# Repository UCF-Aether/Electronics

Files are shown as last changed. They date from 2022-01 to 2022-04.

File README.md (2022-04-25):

<p align="center">
  
</p>

# Aether Electronics
The schematic is viewable as a PDF in the latest release. To view in KiCad, make sure you have KiCad 6 installed, and simply clone the repo and open `aether.kicad_pro`.

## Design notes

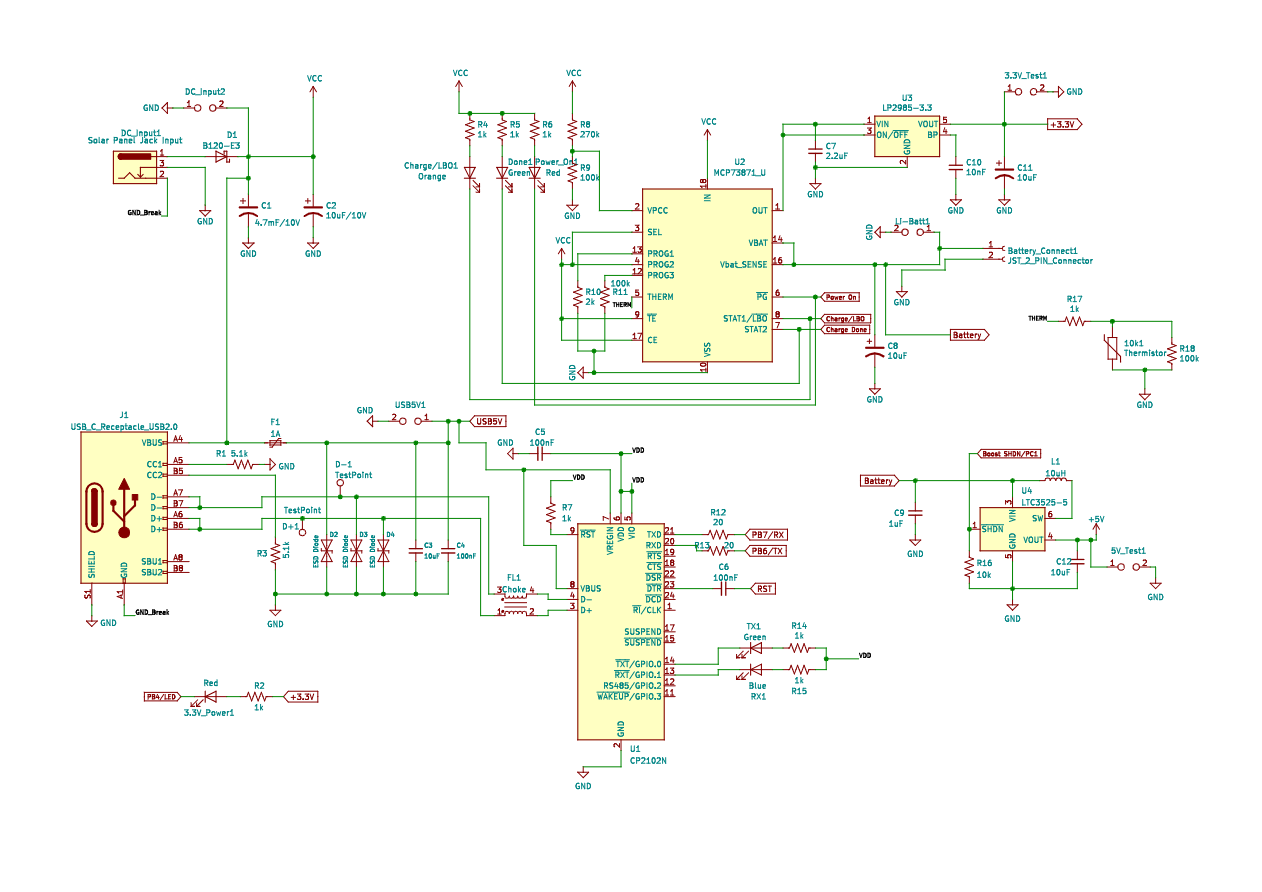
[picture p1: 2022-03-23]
Schematic Images/Power_Schematic_00_00.jpg

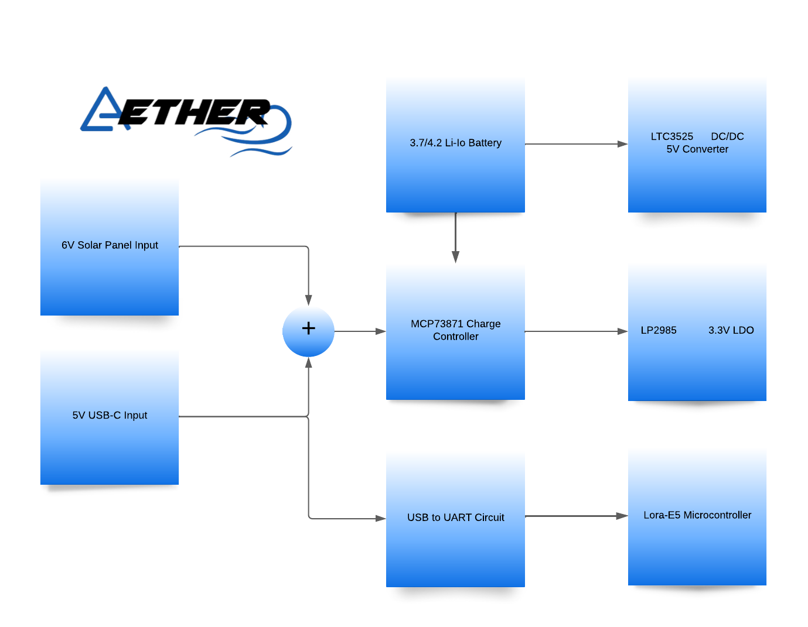
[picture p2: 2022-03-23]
Schematic Images/Aether Power Subsystem Block Diagram.png

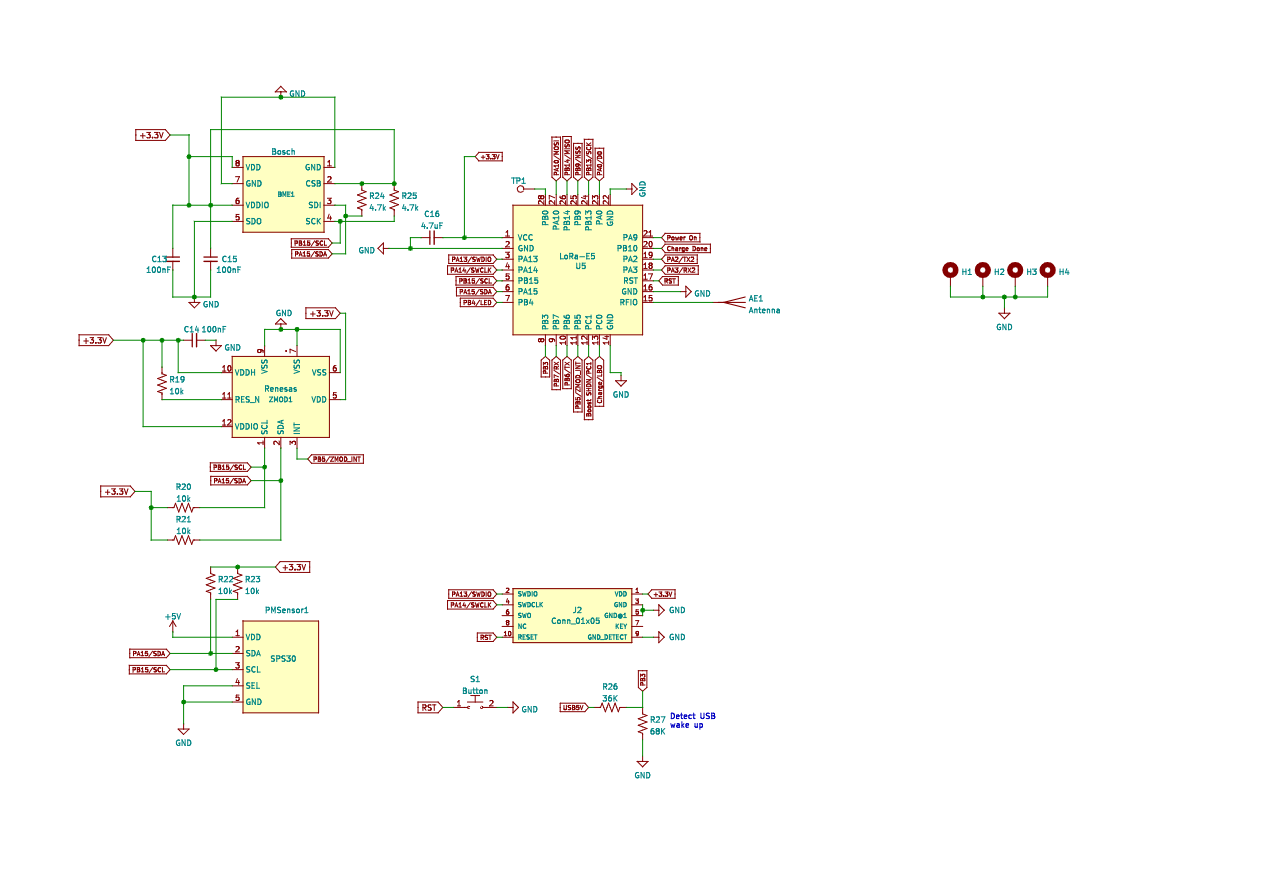
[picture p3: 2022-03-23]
Schematic Images/MCU_Schematic_00_00.jpg

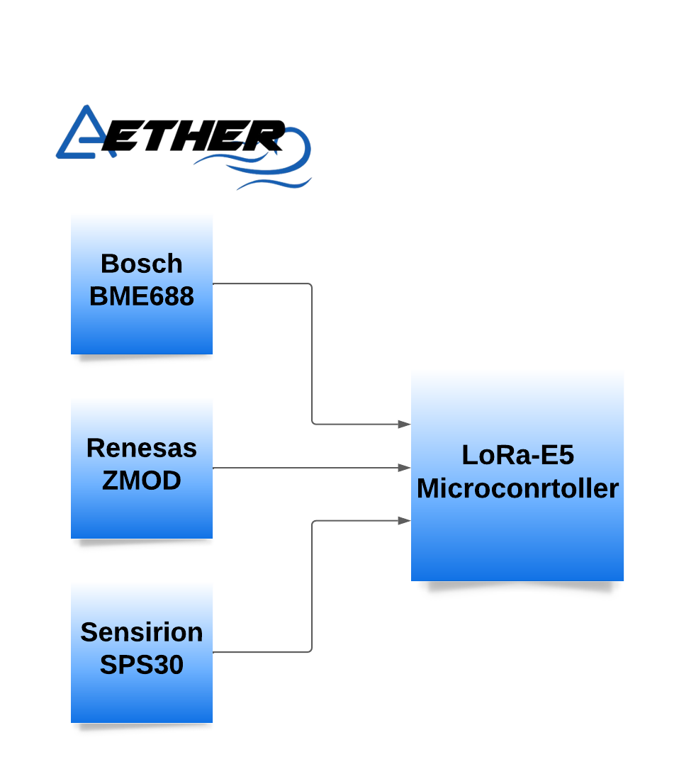
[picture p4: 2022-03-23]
Schematic Images/Aether MCU Subsystem Block Diagram.png

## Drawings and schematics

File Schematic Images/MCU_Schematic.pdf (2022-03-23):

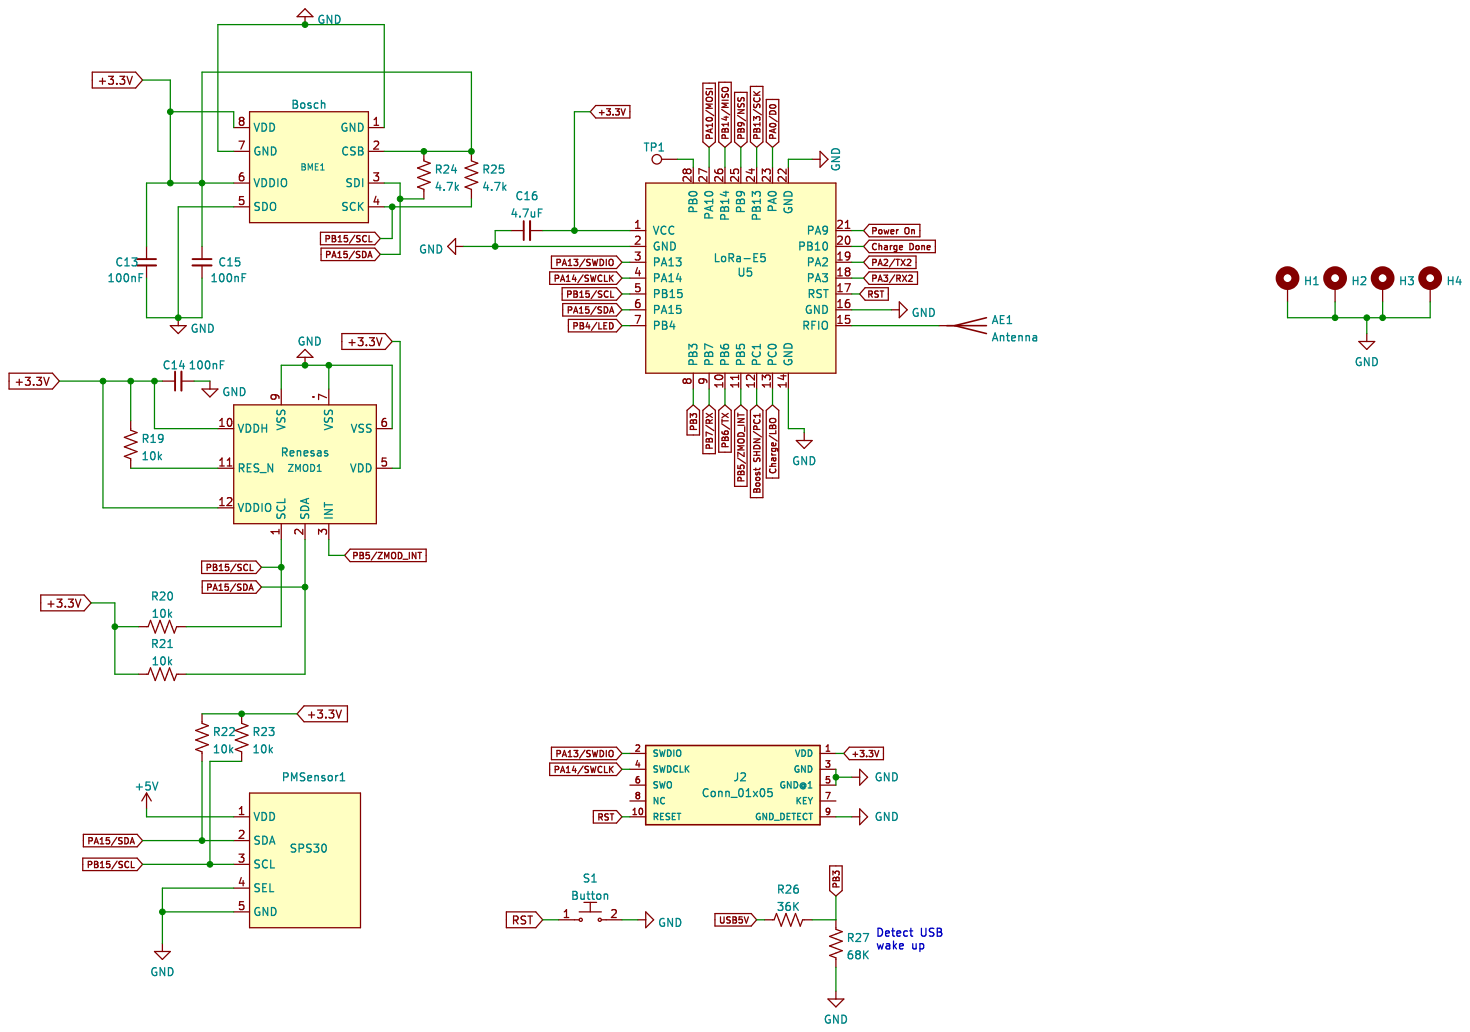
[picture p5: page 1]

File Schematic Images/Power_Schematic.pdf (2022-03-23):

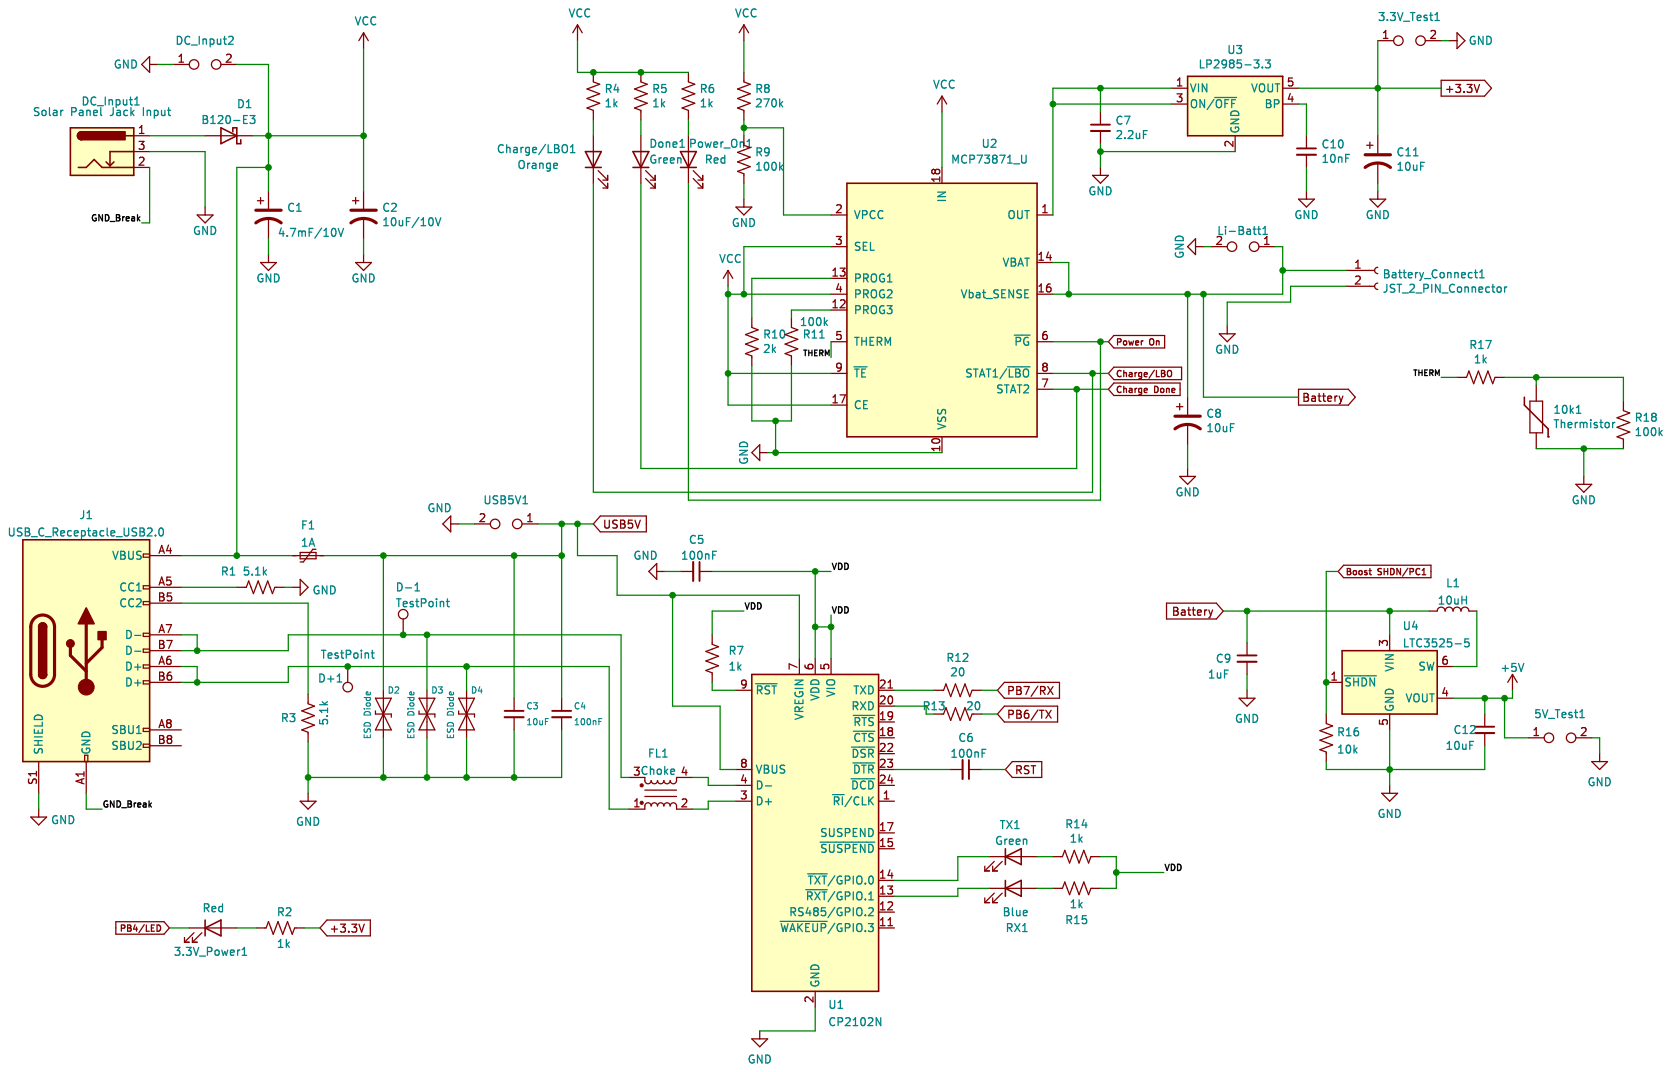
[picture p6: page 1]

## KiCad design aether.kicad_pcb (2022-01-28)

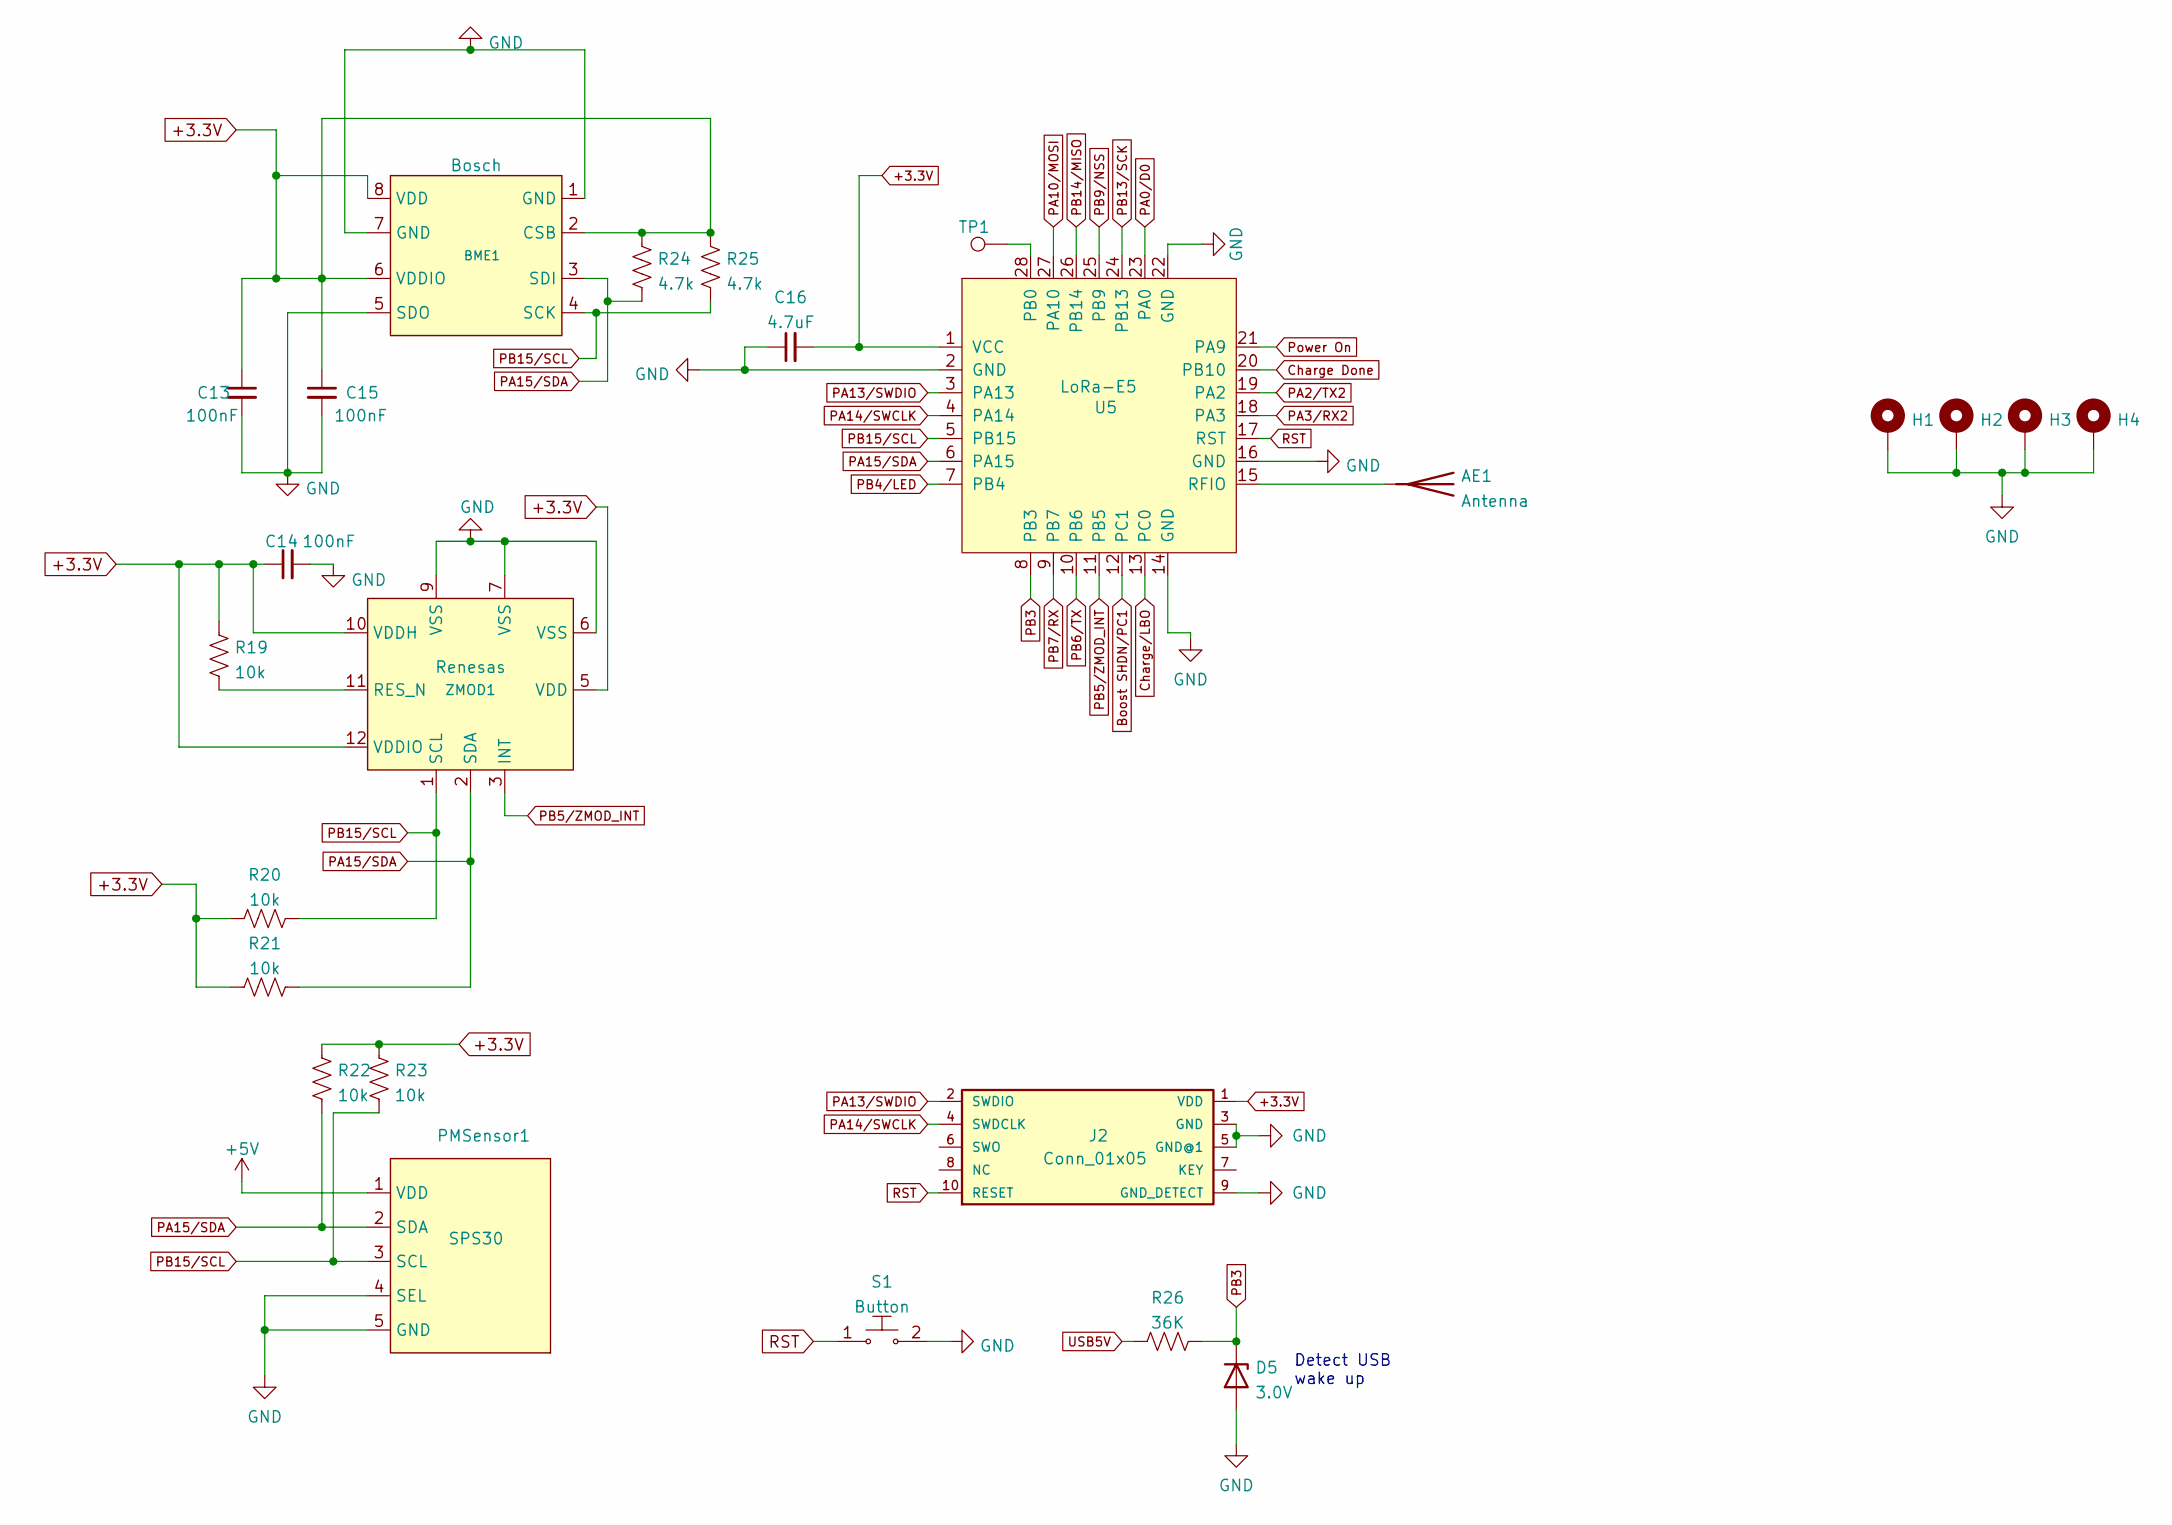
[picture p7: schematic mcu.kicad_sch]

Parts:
AE1: Antenna; SMA_Amphenol_132134_Vertical
BME1: Bosch; Bosch_LGA-8_3x3mm_P0.8mm_ClockwisePinNumbering
C13, C14, C15: 100nF; C_0805_2012Metric_Pad1.18x1.45mm_HandSolder
C16: 4.7uF; C_0805_2012Metric_Pad1.18x1.45mm_HandSolder
D5: 3.0V; D_0805_2012Metric_Pad1.15x1.40mm_HandSolder
H1, H2, H3, H4: MountingHole; MountingHole_2.2mm_M2_ISO14580_Pad_TopBottom
J2: Conn_01x05; 2X10_BOXHEADER
PMSensor1: SPS30; JST_EH_B5B-EH-A_1x05_P2.50mm_Vertical
R19, R20, R21, R22, R23: 10k; R_0805_2012Metric_Pad1.20x1.40mm_HandSolder
R24, R25: 4.7k; R_0805_2012Metric_Pad1.20x1.40mm_HandSolder
R26: 36K; R_0805_2012Metric_Pad1.20x1.40mm_HandSolder
S1: Button; SW_Push_1P1T_NO_6x6mm_H9.5mm; MPN GPTS203211B; Digi-Key_PN CW181-ND
TP1: TestPoint; TestPoint_Keystone_5005-5009_Compact
U5: LoRa-E5
ZMOD1: Renesas; ZMOD4510

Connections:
+3.3V: BME1.2 (CSB), BME1.6 (VDDIO), BME1.8 (VDD), C13.1, C14.1, C15.1, C16.2, J2.1 (VDD), R19.1, R20.1, R21.1, R22.1, R23.1, R24.1, R25.1, U5.1 (VCC), ZMOD1.5 (VDD), ZMOD1.10 (VDDH), ZMOD1.12 (VDDIO); also elsewhere on the board
+5V: PMSensor1.1 (VDD); also elsewhere on the board
Boost SHDN/PC1: U5.12 (PC1); also elsewhere on the board
Charge Done: U5.20 (PB10); also elsewhere on the board
Charge/LBO: U5.13 (PC0); also elsewhere on the board
GND: BME1.1 (GND), BME1.5 (SDO), BME1.7 (GND), C13.2, C14.2, C15.2, C16.1, D5.2 (A), H1.1, H2.1, H3.1, H4.1, J2.3 (GND), J2.5 (GND@1), J2.9 (GND_DETECT), PMSensor1.4 (SEL), PMSensor1.5 (GND), S1.2, U5.2 (GND), U5.14 (GND), U5.16 (GND), U5.22 (GND), ZMOD1.6 (VSS), ZMOD1.7 (VSS), ZMOD1.9 (VSS); also elsewhere on the board
unnamed: AE1.1 (A), U5.15 (RFIO)
unnamed: R19.2, ZMOD1.11 (RES_N)
unnamed: TP1.1, U5.28 (PB0)
PA0/D0: U5.23 (PA0)
PA2/TX2: U5.19 (PA2)
PA3/RX2: U5.18 (PA3)
PA10/MOSI: U5.27 (PA10)
PA13/SWDIO: J2.2 (SWDIO), U5.3 (PA13)
PA14/SWCLK: J2.4 (SWDCLK), U5.4 (PA14)
PA15/SDA: BME1.3 (SDI), PMSensor1.2 (SDA), R21.2, R22.2, R24.2, U5.6 (PA15), ZMOD1.2 (SDA)
PB3: D5.1 (K), R26.2, U5.8 (PB3)
PB4/LED: U5.7 (PB4); also elsewhere on the board
PB5/ZMOD_INT: U5.11 (PB5), ZMOD1.3 (INT)
PB6/TX: U5.10 (PB6); also elsewhere on the board
PB7/RX: U5.9 (PB7); also elsewhere on the board
PB9/NSS: U5.25 (PB9)
PB13/SCK: U5.24 (PB13~)
PB14/MISO: U5.26 (PB14)
PB15/SCL: BME1.4 (SCK), PMSensor1.3 (SCL), R20.2, R23.2, R25.2, U5.5 (PB15), ZMOD1.1 (SCL)
Power On: U5.21 (PA9); also elsewhere on the board
RST: J2.10 (RESET), S1.1, U5.17 (RST); also elsewhere on the board
USB5V: R26.1; also elsewhere on the board

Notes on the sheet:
Detect USB wake up

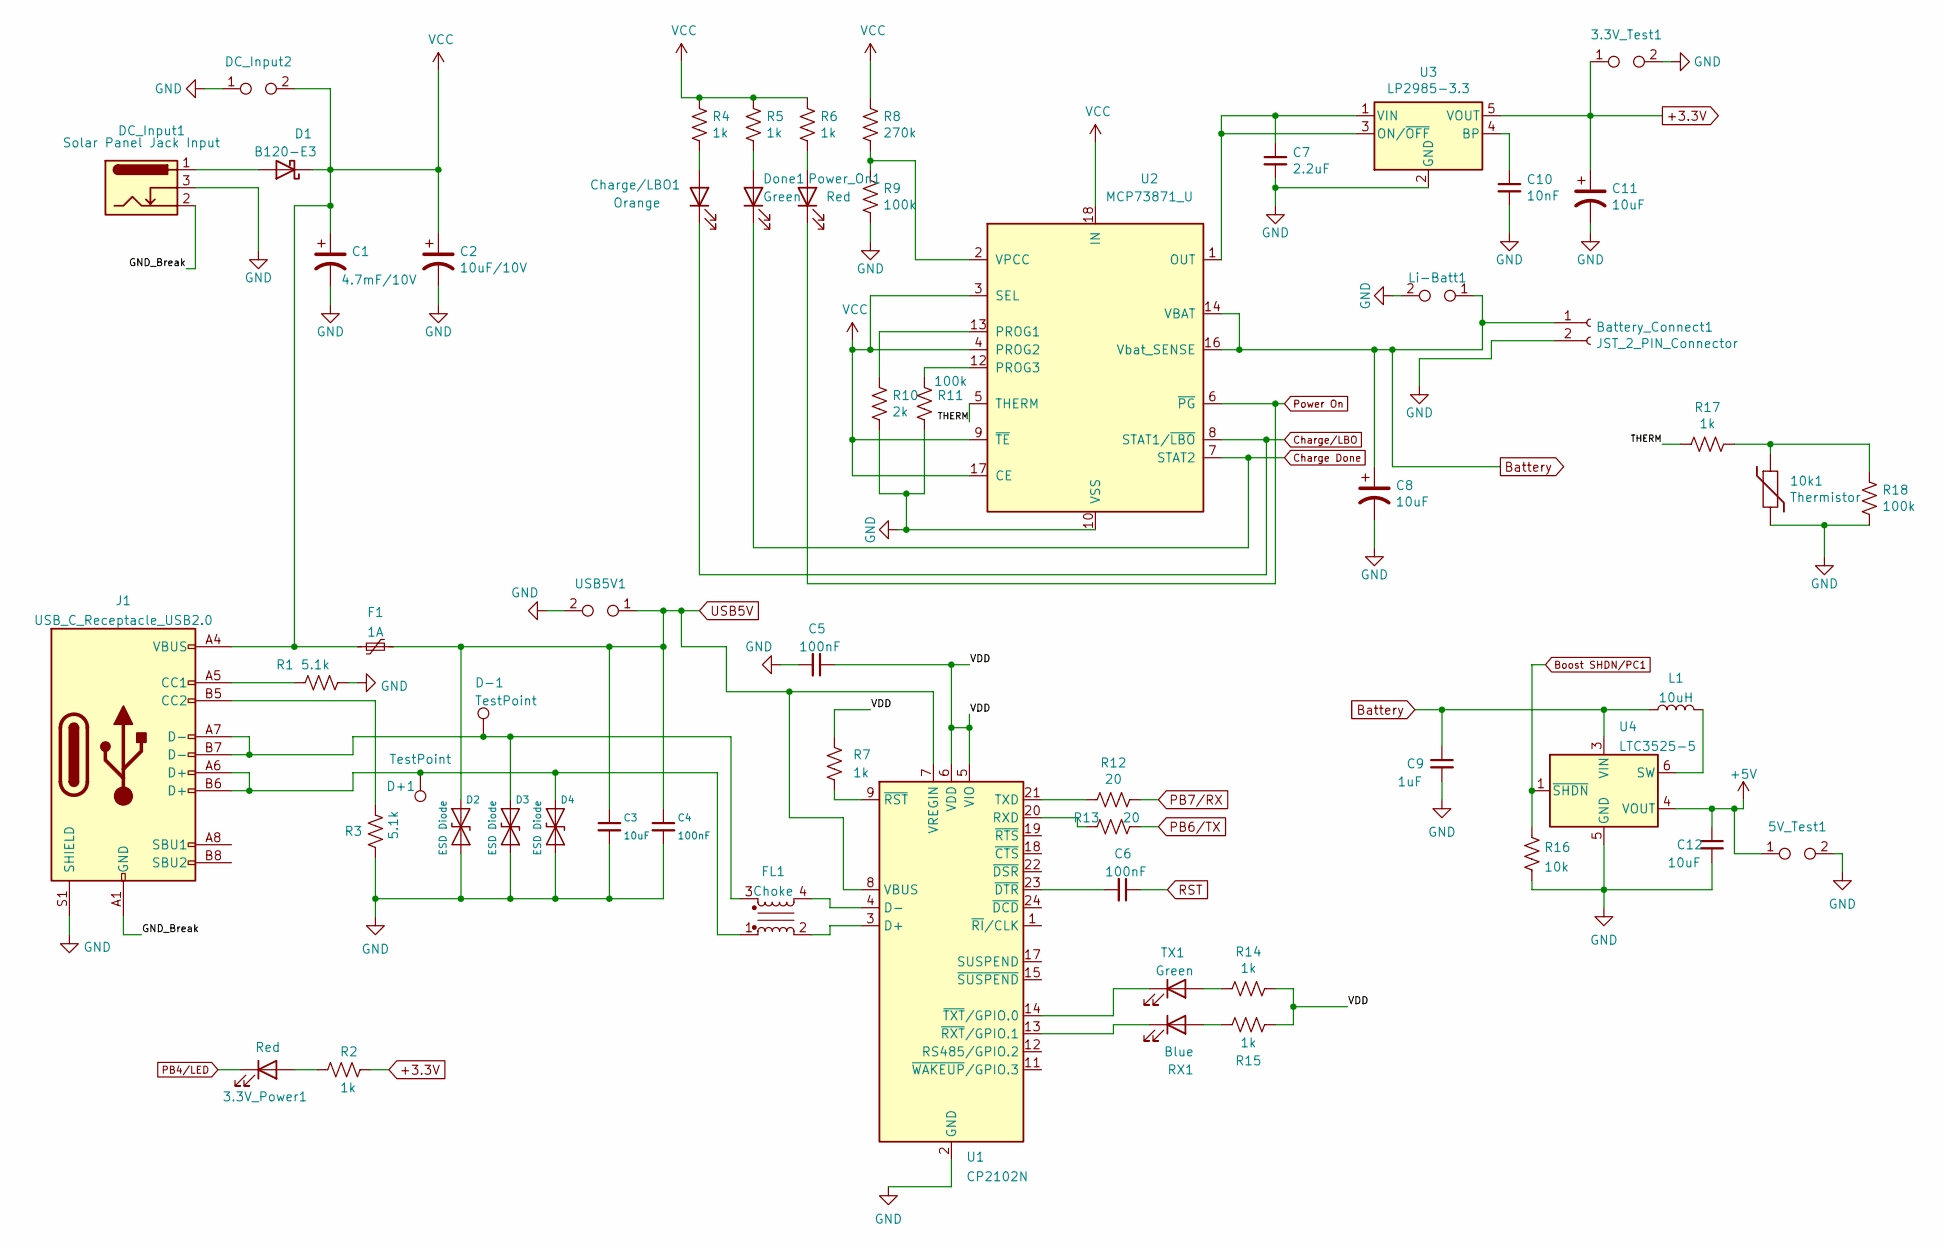
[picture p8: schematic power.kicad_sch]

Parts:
3.3V_Power1: Red; LED_0805_2012Metric_Pad1.15x1.40mm_HandSolder
3.3V_Test1, 5V_Test1: TestPoint; TestPoint_2Pads_Pitch2.54mm_Drill0.8mm
10k1: Thermistor; TerminalBlock_Altech_AK300-2_P5.00mm
Battery_Connect1: JST_2_PIN_Connector; JST_PH_B2B-PH-SM4-TB_1x02-1MP_P2.00mm_Vertical
C1: 4.7mF/10V; CP_Radial_D13.0mm_P5.00mm
C2: 10uF/10V; C_0805_2012Metric_Pad1.18x1.45mm_HandSolder
C3, C8, C11, C12: 10uF; C_0805_2012Metric_Pad1.18x1.45mm_HandSolder
C4, C5, C6: 100nF; C_0805_2012Metric_Pad1.18x1.45mm_HandSolder
C7: 2.2uF; C_0805_2012Metric_Pad1.18x1.45mm_HandSolder
C9: 1uF; C_0805_2012Metric_Pad1.18x1.45mm_HandSolder
C10: 10nF; C_0805_2012Metric_Pad1.18x1.45mm_HandSolder
Charge/LBO1: Orange; LED_0805_2012Metric_Pad1.15x1.40mm_HandSolder
D1: B120-E3; D_SMA
D2, D3, D4: ESD Diode; D_0402_1005Metric_Pad0.77x0.64mm_HandSolder
D+1: TestPoint; TestPoint_Keystone_5000-5004_Miniature
D-1: TestPoint; TestPoint_Keystone_5000-5004_Miniature
DC_Input1: Solar Panel Jack Input; BarrelJack_Horizontal
DC_Input2: TestPoint; TestPoint_2Pads_Pitch2.54mm_Drill0.8mm
Done1: Green; LED_0805_2012Metric_Pad1.15x1.40mm_HandSolder
F1: 1A; Fuse_0805_2012Metric_Pad1.15x1.40mm_HandSolder
FL1: Choke; L_CommonModeChoke_Coilcraft_0805USB
J1: USB_C_Receptacle_USB2.0; USB_C_Receptacle_XKB_U262-16XN-4BVC11
L1: 10uH; L_0805_2012Metric_Pad1.15x1.40mm_HandSolder
Li-Batt1: TestPoint; TestPoint_2Pads_Pitch2.54mm_Drill0.8mm
Power_On1: Red; LED_0805_2012Metric_Pad1.15x1.40mm_HandSolder
R1, R3: 5.1k; R_0805_2012Metric_Pad1.20x1.40mm_HandSolder
R2, R4, R5, R6, R7, R14, R15, R17: 1k; R_0805_2012Metric_Pad1.20x1.40mm_HandSolder
R8: 270k; R_0805_2012Metric_Pad1.20x1.40mm_HandSolder
R9, R11, R18: 100k; R_0805_2012Metric_Pad1.20x1.40mm_HandSolder
R10: 2k; R_0805_2012Metric_Pad1.20x1.40mm_HandSolder
R12, R13: 20; R_0805_2012Metric_Pad1.20x1.40mm_HandSolder
R16: 10k; R_0805_2012Metric_Pad1.20x1.40mm_HandSolder
RX1: Blue; LED_0805_2012Metric_Pad1.15x1.40mm_HandSolder
TX1: Green; LED_0805_2012Metric_Pad1.15x1.40mm_HandSolder
U1: CP2102N; QFN-24-1EP_4x4mm_P0.5mm_EP2.6x2.6mm
U2: MCP73871_U; QFN-20-1EP_4x4mm_P0.5mm_EP2.5x2.5mm
U3: LP2985-3.3; SOT-23-5
U4: LTC3525-5; SOT-363_SC-70-6
USB5V1: TestPoint; TestPoint_2Pads_Pitch2.54mm_Drill0.8mm

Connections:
+3.3V: 3.3V_Test1.1, C11.1, R2.2, U3.5 (VOUT); also elsewhere on the board
+5V: 5V_Test1.1, C12.1, U4.4 (VOUT); also elsewhere on the board
/Power/GND_Break: DC_Input1.2, J1.A1 (GND), J1.A12 (GND), J1.B1 (GND), J1.B12 (GND)
/Power/THERM: R17.2, U2.5 (THERM)
/Power/VDD: C5.1, R7.2, R14.1, R15.1, U1.5 (VIO), U1.6 (VDD)
Battery: Battery_Connect1.1, C8.1, C9.1, L1.1, Li-Batt1.1, U2.14 (VBAT), U2.15 (VBAT), U2.16 (Vbat_SENSE), U4.3 (VIN)
Boost SHDN/PC1: R16.1, U4.1 (~SHDN); also elsewhere on the board
Charge Done: Done1.1 (K), U2.7 (STAT2); also elsewhere on the board
Charge/LBO: Charge/LBO1.1 (K), U2.8 (STAT1/~LBO); also elsewhere on the board
GND: 3.3V_Test1.2, 5V_Test1.2, 10k1.2, Battery_Connect1.2, C1.2, C2.2, C3.2, C4.2, C5.2, C7.2, C8.2, C9.2, C10.2, C11.2, C12.2, D2.2 (A2), D3.2 (A2), D4.2 (A2), DC_Input1.3, DC_Input2.1, J1.S1 (SHIELD), Li-Batt1.2, R1.1, R3.1, R9.1, R10.1, R11.1, R16.2, R18.1, U1.2 (GND), U1.25 (GND), U2.10 (VSS), U2.11 (VSS), U2.21 (VSS), U3.2 (GND), U4.2 (GND), U4.5 (GND), USB5V1.2; also elsewhere on the board
unnamed: 3.3V_Power1.2 (A), R2.1
unnamed: 10k1.1, R17.1, R18.2
unnamed: C6.2, U1.23 (~DTR)
unnamed: C7.1, U2.1 (OUT), U2.20 (OUT), U3.1 (VIN), U3.3 (ON/~OFF)
unnamed: C10.1, U3.4 (BP)
unnamed: Charge/LBO1.2 (A), R4.1
unnamed: D1.2 (A), DC_Input1.1
unnamed: D4.1 (A1), D+1.1, FL1.1, J1.A6 (D+), J1.B6 (D+)
unnamed: D3.1 (A1), D-1.1, FL1.3, J1.A7 (D-), J1.B7 (D-)
unnamed: Done1.2 (A), R5.1
unnamed: FL1.2, U1.3 (D+)
unnamed: FL1.4, U1.4 (D-)
unnamed: J1.A5 (CC1), R1.2
unnamed: J1.B5 (CC2), R3.2
unnamed: L1.2, U4.6 (SW)
unnamed: Power_On1.2 (A), R6.1
unnamed: R7.1, U1.9 (~RST)
unnamed: R8.1, R9.2, U2.2 (VPCC)
unnamed: R10.2, U2.13 (PROG1)
unnamed: R11.2, U2.12 (PROG3)
unnamed: R12.2, U1.21 (TXD)
unnamed: R13.2, U1.20 (RXD)
unnamed: R14.2, TX1.2 (A)
unnamed: R15.2, RX1.2 (A)
unnamed: RX1.1 (K), U1.13 (~RXT/GPIO.1)
unnamed: TX1.1 (K), U1.14 (~TXT/GPIO.0)
PB4/LED: 3.3V_Power1.1 (K); also elsewhere on the board
PB6/TX: R13.1; also elsewhere on the board
PB7/RX: R12.1; also elsewhere on the board
Power On: Power_On1.1 (K), U2.6 (~PG); also elsewhere on the board
RST: C6.1; also elsewhere on the board
USB5V: C3.1, C4.1, D2.1 (A1), F1.2, U1.7 (VREGIN), U1.8 (VBUS), USB5V1.1; also elsewhere on the board
VCC: C1.1, C2.1, D1.1 (K), DC_Input2.2, F1.1, J1.A4 (VBUS), J1.A9 (VBUS), J1.B4 (VBUS), J1.B9 (VBUS), R4.2, R5.2, R6.2, R8.2, U2.3 (SEL), U2.4 (PROG2), U2.9 (~TE), U2.17 (CE), U2.18 (IN), U2.19 (IN)

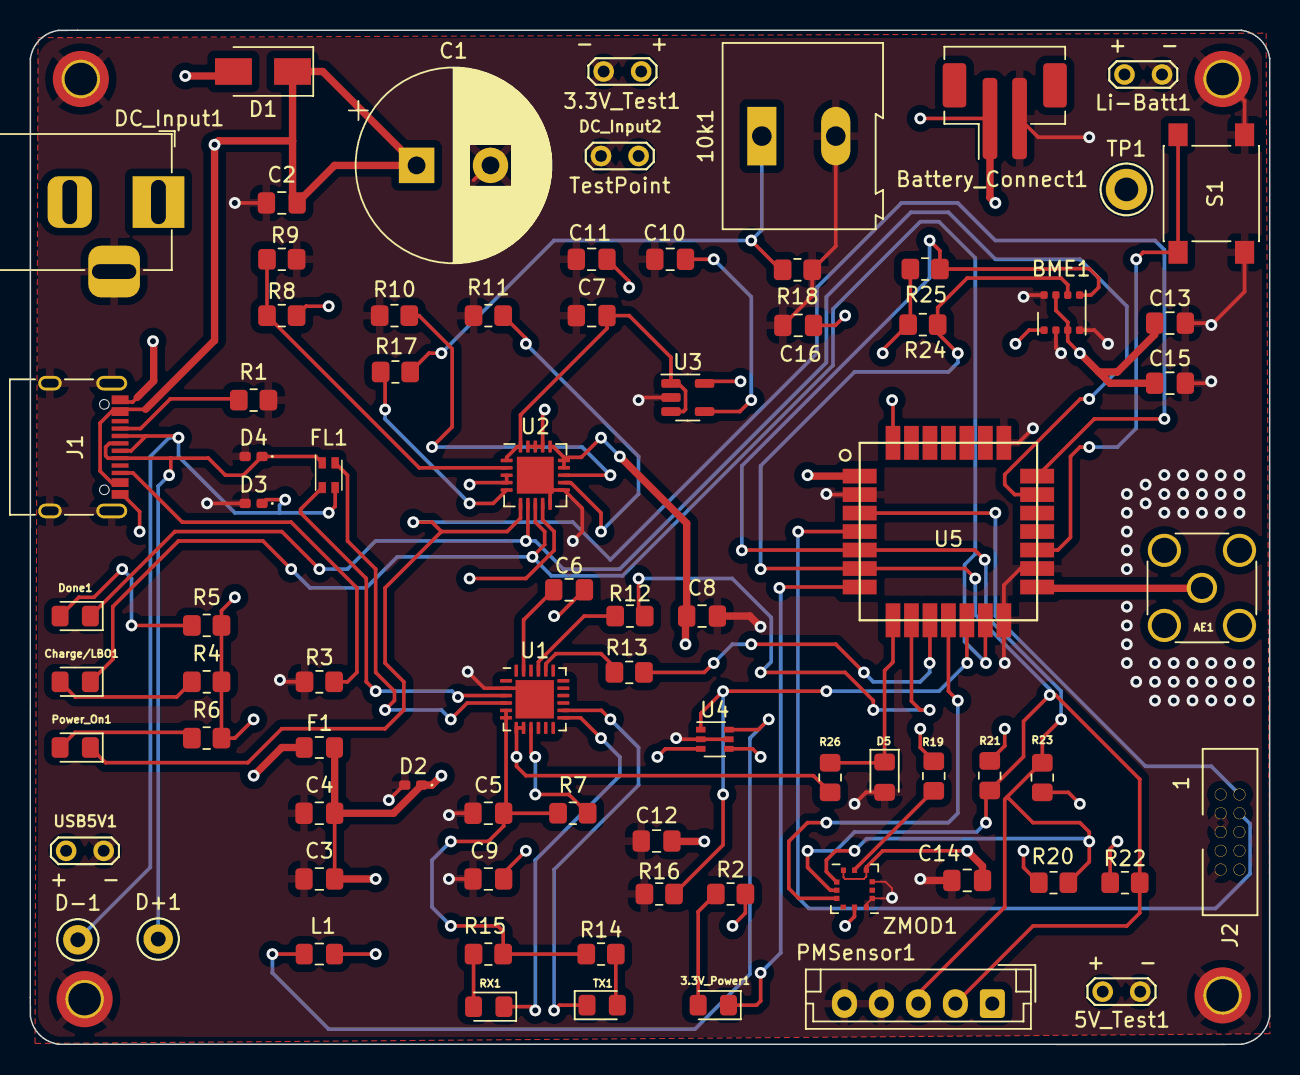
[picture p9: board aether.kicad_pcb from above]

Board: 4 copper layers, 83.8 x 68.6 mm, 83 parts (0 on the bottom side), 52 nets.

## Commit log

2021-10-21 init: blank kicad project
    [UCF-SAQS.kicad_pcb, UCF-SAQS.sch]
2021-10-26 lib: added lora-e5
    [UCF-SAQS.kicad_pcb, UCF-SAQS.sch, aether.kicad_pcb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]
2021-10-27 feat: added gitignores for kicad 5.99/6.0
2021-10-27 sch: start lora module
    [aether.kicad_sch]
2021-11-28 Reorganized repo & added power schematic
    [aether.kicad_pcb, aether.kicad_sch, power.kicad_sch]
2021-11-28 Added Digikey library
    - Added to symbol and footprint tables
    - Using fork updated for KiCad 6
2021-11-28 Added MCU sch sheet and updated sheet layout
    [aether.kicad_sch, mcu.kicad_sch, power.kicad_sch]
2021-11-30 Created Sensor Library
    - Added Bosch BME688, SPS30, ZMOD symbols to MCU schematic
    [aether.kicad_sch, mcu.kicad_sch, power.kicad_sch]
2021-12-01 Connected ZMOD and Bosch Sensors
    -
    [aether.kicad_sch, mcu.kicad_sch, power.kicad_sch]
2021-12-02 USB Comm Interface complete; Sensor and MCU connection complete;
    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
    [aether.kicad_sch, mcu.kicad_sch, power.kicad_sch]
2021-12-04 A few schematic changes and fixes
    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
    [aether.kicad_sch, mcu.kicad_sch, power.kicad_sch]
2021-12-07 -
    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
    [aether.kicad_sch, mcu.kicad_sch, power.kicad_sch]
2021-12-07 USB updated. All footprints added for the most part
    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
    [aether.kicad_sch, mcu.kicad_sch, power.kicad_sch]
2022-01-02 Some schematic changes. Preliminary PCB layout complete, routing not done yet
    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
    [aether.kicad_pcb, aether.kicad_sch, mcu.kicad_sch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]
2022-01-03 Generated more 3d models for pcb
    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
    [aether.kicad_pcb, aether.kicad_sch, mcu.kicad_sch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]
2022-01-14 PCB edits
    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
    [aether.kicad_pcb, aether.kicad_sch, mcu.kicad_sch]
2022-01-18 Rearranged PCB for more efficient routing
    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
    [aether.kicad_pcb, aether.kicad_sch, mcu.kicad_sch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]
2022-01-18 PCB Routed
    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
    [aether.kicad_pcb, aether.kicad_sch, mcu.kicad_sch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]
2022-01-21 DRC runs with 0 Errors. Updates connections and footprints.
    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
    [aether.kicad_pcb, aether.kicad_sch, mcu.kicad_sch]
2022-01-28 Edits
    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
    [aether-B_Cu.gbr, aether-B_Mask.gbr, aether-B_Silkscreen.gbr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]
2022-04-24 Updated Schematics
    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
    [aether.kicad_sch, mcu.kicad_sch]
2022-04-25 Final Schematic
    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
    [aether.kicad_sch, mcu.kicad_sch, power.kicad_sch]
